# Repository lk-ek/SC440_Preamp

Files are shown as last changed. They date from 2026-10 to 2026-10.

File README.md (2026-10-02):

# SC440 OPA1678 microphone preamp

## don't try this at home

Caveat: measurements show that the theoretical use for this preamp is a
reduction of the noise floor by a whopping 0.2dB. The noise seems to come from
either the capsule or the analog board.

So this is a nice flex mod as an exercise in analogue circuitry, but don't
expect any quality gains from it at all.

## Intro

A 5 V analog gain board for the **t.bone SC 440 USB microphone**. It sits between
its original microphone/JFET board and USB/ADC board, AC-couples the signal,
rebiases it around a buffered half-supply reference, and adds selectable gain.
The aim is to use less gain in the following ADC stage. A reduction in overall
recording noise depends on how much noise that stage contributes; microphone
and original analog-board noise are amplified along with the signal.

**Default in the current KiCad files:** amplifier gain +10.10 dB, using R8 = 2.2 kΩ and
R9 = 1 kΩ, with the C2 = 1 µF MLCC input option. C1, R1 and R2 are DNP.
C9 = 330 pF is populated across R8.

The board outline is **30 × 35 mm**, with 2 mm corner radii. PCB thickness in
this project is **1.6 mm**. Files were saved with **KiCad 10.99 nightly**; use a
build that supports their file format.

- [Assembly choices: gain and input capacitor](#assembly-choices)
- [Bill of materials](#bill-of-materials)
- [Connections and installation](#connections-and-installation)
- [Circuit and test points](#circuit-and-test-points)
- [Views](#views)
- [Simulation](#simulation)
- [Regenerating the README images](#regenerating-the-readme-images)

## Assembly choices

### Gain: approximately 6, 8 or 10 dB

The non-inverting amplifier uses `Av = 1 + R8/R9`, with R9 fixed at **1 kΩ**.
Populate one R8 value; these are alternatives, not additional resistors.

| Variant | R8 | R9 | Voltage gain | Gain | Concrete R8 example, Yageo thin film |
|---|---:|---:|---:|---:|---|
| 6 dB | 1 kΩ | 1 kΩ | 2.0× | +6.02 dB | `RT0805BRD071KL` |
| 8 dB | 1.5 kΩ | 1 kΩ | 2.5× | +7.96 dB | `RT0805BRD071K5L` |
| **10 dB — CAD default** | **2.2 kΩ** | **1 kΩ** | **3.2×** | **+10.10 dB** | `RT0805BRD072K2L` |

The table gives the amplifier gain. End-to-end gain from J2 pin 4 to J1 pin 4
is slightly lower: R4/R6 alone introduce about 0.086 dB attenuation. The
unloaded AC model gives approximately **5.93 / 7.87 / 10.01 dB at 1 kHz**
for the default MLCC option. See [SIMULATION_VALIDATION.md](SIMULATION_VALIDATION.md)
for both capacitor options and the 20 kHz results.

These parts are 0805, 0.1%, 25 ppm/°C, 0.125 W. Ordinary 1% resistors also work;
thin film is preferred for R8/R9 for ratio stability and low excess noise.
Thin film does not eliminate thermal noise. The lower resistance values reduce
that contribution compared with the older 22 kΩ/10 kΩ pair.

Use 6 dB where input-level headroom matters most; 10 dB provides the greatest
analog boost. For a fixed ADC clipping level, allowable microphone-board input
amplitude is inversely proportional to the selected voltage gain. Reduce ADC
gain to obtain comparable recording levels, then check loud speech and plosives.
An analog booster does not increase the ADC's full-scale voltage.

**C9 remains 330 pF for all three variants.** Its feedback-network pole is
approximately 482 kHz / 322 kHz / 219 kHz for 6 / 8 / 10 dB respectively. This
reduces the ideal amplifier gain toward unity at high frequencies; it is not a
filter whose gain falls to zero. Its calculated contribution at 20 kHz is only
about −0.006 / −0.014 / −0.032 dB respectively, before other circuit roll-off.

### Input coupling: MLCC or film

Choose exactly one of the following assemblies. The input resistor R4 and bias
resistor R6 are unchanged for either option.

| Part | **A — compact MLCC, CAD default** | **B — film** |
|---|---|---|
| C2 | **1 µF, 0805, X7R**, ≥16 V | **DNP** |
| C1 | DNP | **2.2 µF PET film**, Faratronic `C241J225J2SC000`, 63 V, 5 mm pitch |
| R1, R2 | DNP | **0 Ω each**, 0805 |
| R4 | 1 kΩ | 1 kΩ |
| R6 | 100 kΩ | 100 kΩ |
| Approximate input high-pass pole | 1.6 Hz | 0.72 Hz |

The default path is C2 → R4 → IN_AC. The film path is
R1 → C1 → R2 → R4 → IN_AC. Do not populate both coupling branches: the two
capacitors would operate in parallel rather than select a single option.

Both coupling capacitors are non-polarized. Film avoids the ferroelectric
voltage dependence and microphony of X7R, but takes more space. The MLCC option
is the compact assembly; its effective capacitance depends on the exact part
and bias. These differences do not by themselves establish an audible benefit
in the complete microphone.

The film variant requires assembly changes only. If editing KiCad to represent
that variant, mark C2 DNP and clear DNP on C1/R1/R2, then update the PCB from the
schematic. C1/R1/R2 are currently excluded from simulation as well, so changing
DNP flags alone is not sufficient to simulate the film path.

## Bill of materials

Quantities below are **per preamp PCB**. They describe the current electrical
values and footprints. Orderable examples are documented choices, not proof
that those exact manufacturers are already installed. Equivalent parts must
match value, dielectric/technology, package and mechanical clearance.

All SMD passives use **0805 hand-solder footprints**. Resistor examples are
0.125 W. No special “audio-grade” electrolytics are needed. Prices and stock
are intentionally not fixed in this BOM.

### Common parts for all six gain/capacitor combinations

| Ref. | Qty | Value / specification | Package / assembly side | Concrete part or ordering specification |
|---|---:|---|---|---|
| U1 | 1 | OPA1678 dual audio op-amp | SOIC-8, 3.9 × 4.9 mm, 1.27 mm pitch; front | **Texas Instruments `OPA1678IDR`**; do not substitute VSSOP/SON versions |
| R3 | 1 | 22 Ω, 1% | 0805; front | Yageo `RC0805FR-0722RL` |
| R4, R9 | 2 | 1 kΩ; thin film, 0.1% recommended | 0805; front | Yageo **`RT0805BRD071KL`**; thin film at R4 is optional |
| R5, R7 | 2 | 10 kΩ, 1% | 0805; front | Yageo `RC0805FR-0710KL` |
| R6 | 1 | 100 kΩ, 1% | 0805; front | Yageo `RC0805FR-07100KL` |
| R8 | 1 | **Select 1 kΩ / 1.5 kΩ / 2.2 kΩ** | 0805; front | Select exactly one part from the gain table above |
| R10 | 1 | 100 Ω, 1% | 0805; front | Yageo `RC0805FR-07100RL` |
| C3 | 1 | 47 µF, 16 V, ±20%, polarized | Radial, Ø5 × 11 mm, 2 mm pitch; front | **Aishi `ERS1CM470D11OT`**, [LCSC C160836](https://www.lcsc.com/product-detail/C160836.html), matching the schematic link |
| C4, C8 | 2 | 100 nF, X7R, ±10%, ≥16 V | 0805; **C4 front, C8 back** | Example: Murata `GRM21BR71H104KA01L`, 50 V |
| C5, C9 | 2 | 330 pF, **C0G/NP0**, ±5% | 0805; front | Example: Murata **`GRM2165C2A331JA01D`**, 100 V |
| C6 | 1 | 10 µF, 16 V, ±20%, polarized | Radial, Ø5 × 11 mm, 2 mm pitch; front, **mount lying down** | **Chengx `KM106M016D11RR0VH2FP0`**, [LCSC C43799](https://www.lcsc.com/product-detail/C43799.html), matching the schematic link |
| C7 | 1 | 1 nF, **C0G/NP0**, ±5% | 0805; front | Example: Murata **`GRM2165C2A102JA01D`**, 100 V |
| J1 | 1 | 4-pin JST XH header to digital board | **2.50 mm**, vertical/top-entry; back | **JST `B4B-XH-A`**; RoHS/tinning suffix may be shown as `(LF)(SN)` |
| J2 | 1 | 4-pin male header to analog board | **2.54 mm**, straight; back | 1×4, 0.64 mm square pins; cut from a standard strip; choose mating length to suit original socket and board spacing |
| TP1–TP5 | 5 PCB pads | Test pads, no purchased component required | 1 × 1 mm THT pad, 0.5 mm drill; front | Optional fine wire for probing; not five additional headers |

**C4 and C8 are required bypass capacitors and are included in the BOM.** Their
previous exclusion flags have been cleared in the root schematic, PCB and
synchronized AC schematic.

C3 alternative: **Rubycon `35ZLH47MEFC5X11`**, 47 µF / 35 V, Ø5 × 11 mm,
2 mm pitch, [LCSC C109390](https://www.lcsc.com/product-detail/C109390.html).
It fits the nominal pad pitch/body diameter and is electrically suitable;
ZLH is a low-impedance series, not a dedicated low-leakage series. The higher
voltage rating is not necessary here. Low leakage is useful at VREF_RAW, but a
standard good-quality aluminum electrolytic is sufficient for this application.

### Add parts for exactly one input option

| Variant | Ref. | Qty | Specification | Concrete example |
|---|---|---:|---|---|
| **A — MLCC** | C2 | 1 | 1 µF, X7R, ±10%, 0805, ≥16 V | Murata **`GRM219R71E105KA88D`**, 25 V |
| **B — film** | C1 | 1 | 2.2 µF, PET, ±5%, 63 V, 5 mm lead pitch | Faratronic **`C241J225J2SC000`**, [LCSC C5372007](https://www.lcsc.com/product-detail/C5372007.html) |
| **B — film** | R1, R2 | 2 | 0 Ω links, 0805 | Yageo **`RC0805JR-070RL`**, or suitable solder bridges |

The MLCC assembly has **14 SMD passives and two radial electrolytics**. The film
assembly has **15 SMD passives, two radial electrolytics and one film capacitor**.
Both also use U1, J1 and J2. Simulation sources and XREF1/XAMP1 are not physical
parts to order.

### Cable, original-board modification and mechanical supports

| Item | Qty per complete installation | Concrete choice / notes |
|---|---:|---|
| Additional digital-board header | 1 | JST **`B4B-XH-A`**, if replacing the original digital-board socket as described below; verify its hole spacing separately |
| Cable housings | 2 | JST **`XHP-4`**, 4 positions |
| Crimp contacts | 8 | JST **`SXH-001T-P0.6`**, for 22–28 AWG wire; use the matching crimp tooling, or a correctly wired premade XH cable |
| Cable conductors | 4 | Short flexible wires; verify pin-to-pin continuity rather than trusting wire colors |
| Replacement analog-board header | As required | Standard 2.54 mm 1×4 header; original connector relocation is part of the installation, not an extra gain-stage component |
| PCB-only support footprints | 2, optional mechanical population | Two back-side **1×2, 2.54 mm pin sockets**, currently both called `REF**`; their pads have **no electrical nets**. Select height to suit the original board or leave unpopulated if not needed for support |

Part references: [TI OPA1678 datasheet](https://www.ti.com/lit/ds/symlink/opa1678.pdf),
[JST XH datasheet](https://www.jst-mfg.com/product/pdf/eng/eXH.pdf),
[Yageo 2.2 kΩ RT specification](https://www.yageogroup.com/component-documentation/download/specsheet/RT0805BRD072K2L),
[Yageo 1.5 kΩ RT specification](https://www.yageogroup.com/component-documentation/download/specsheet/RT0805BRD071K5L),
[Yageo 1 kΩ RT specification](https://www.yageogroup.com/component-documentation/download/specsheet/RT0805BRD071KL),
[Murata MLCC catalog, including C0G parts](https://www.mouser.com/datasheet/2/281/murata_mure-s-a0000034126-1-1740300.pdf),
and [Murata 100 nF specification](https://search.murata.co.jp/Ceramy/image/img/A01X/G101/ENG/GRM21BR71H104KA01-01.pdf).
See [FOOTPRINT_CHECK.md](FOOTPRINT_CHECK.md) for the actual symbol/pad/device cross-check.

## Connections and installation

### Connector pinout

**J1 is the digital-board connector; J2 is the analog-board connector.** Both
are installed on the **back** of this PCB. The two pitches differ: JST XH is
2.50 mm, the unshrouded analog header is 2.54 mm.

| Pin number | J2 — from analog board | J1 — to digital board | Connection on this PCB |
|---|---|---|---|
| 1 | GND | GND | Direct common ground |
| 2 | LED | LED | Direct pass-through |
| 3 | +5V | +5V | Direct pass-through; preamp supply branches through R3 |
| 4 | ANALOG_INPUT | ANALOG_OUTPUT | Through coupling capacitor, amplifier and R10; **not** direct |

Use pad numbers, including the square pin-1 pad, rather than assuming a
left-to-right order from a photograph. Back-side placement and mirrored views
change the apparent order. Check the cable at both ends before connecting USB.

The intended installation mounts the daughterboard behind the original analog
PCB. Remove/reposition the original analog-board pin headers to the opposite
side to make the required board-to-board connection. Replace the original
digital-board pin socket with a JST XH header and use a short 4-wire cable to
J1. Verify actual original-board holes, mating parts and enclosure clearance
before final soldering; the daughterboard files do not define those original
board footprints.

**Keep the existing series DC-blocking capacitor on the digital-board audio
input.** J1 pin 4 carries the amplified AC signal on a DC level near VREF. There
is no output coupling capacitor on the daughterboard itself. The microphone's
exact ADC-side connection must be checked on the physical digital board.

C6 needs to be mounted **lying down** in the intended enclosure. Its CAD model
is a generic upright radial capacitor, so the 3D view is not the final assembly
orientation. Preserve polarity, avoid stressing the lead seals, and keep the
body/metalwork clear of exposed conductors. Check C3 and the optional C1 against
available height too. C1 currently has no attached 3D model.

## Circuit and test points

| Block | Actual parts / connections | Purpose / approximate behavior |
|---|---|---|
| Supply filter | R3 = 22 Ω; C6 = 10 µF and C8 = 100 nF from VCC_A to GND | Filters raw USB 5 V; ideal R3/C6 pole ≈723 Hz |
| Reference divider | R5 = 10 kΩ from VCC_A to VREF_RAW; R7 = 10 kΩ to GND; C3 = 47 µF and C4 = 100 nF to GND | Approximately VCC_A/2; divider/C3 pole ≈0.68 Hz |
| Reference buffer | U1B: pin 5 at VREF_RAW, pins 6/7 at VREF | Low-impedance reference for input bias and feedback |
| Input coupling / bias | C2 or C1/R1/R2; R4 = 1 kΩ; R6 = 100 kΩ to VREF | Blocks original-board DC and establishes the amplifier bias |
| Input RF filter | R4 with C5 = 330 pF from IN_AC to GND | Pole approximately 0.48 MHz for a low-impedance source; source impedance also matters |
| Amplifier | U1A; R8 from PREAMP_OUT to FB, R9 from FB to VREF | Gain selected by R8/R9 |
| Feedback HF shaping | C9 = 330 pF parallel to R8 | Gradually reduces gain toward unity above the feedback pole |
| Output isolation / filter | R10 = 100 Ω; C7 = 1 nF from ANALOG_OUTPUT to GND | Isolates capacitive cable/input load; ideal RC pole ≈1.59 MHz |

These pole calculations describe individual networks, not the complete loaded
frequency response. Cable/ADC loading and the op-amp's finite bandwidth also
contribute. Do not add a large capacitor directly to the buffered VREF output
without checking the buffer's capacitive-load stability; C3/C4 are on VREF_RAW.

| Test pad | Net | Expected DC with USB connected, no audio |
|---|---|---|
| TP1 | VCC_A | Raw +5V minus the drop across R3; **at least 4.5 V** for OPA1678 operation |
| TP2 | VREF_RAW | Approximately TP1/2 |
| TP3 | VREF | Approximately TP2 |
| TP4 | PREAMP_OUT | Approximately TP3 |
| TP5 | GND | Probe reference |

Raw USB voltage was reported above 4.9 V. At roughly 4.2 mA quiescent draw the
22 Ω resistor drops about 0.09 V; this is an estimate, not a minimum-voltage
measurement at the IC. Check TP1 under operation. The input signal is centered
near half supply; OPA1678 is not rail-to-rail at its inputs.

For commissioning, first check power and reference voltages, then compare
recordings at equal final level with reduced ADC gain. Check clipping with loud
speech/plosives and look for USB-related spurs. A valid rendering or simulated
trace does not replace those measurements.

## Views

The included images represent the saved default assembly (10 dB, MLCC).

### Schematic

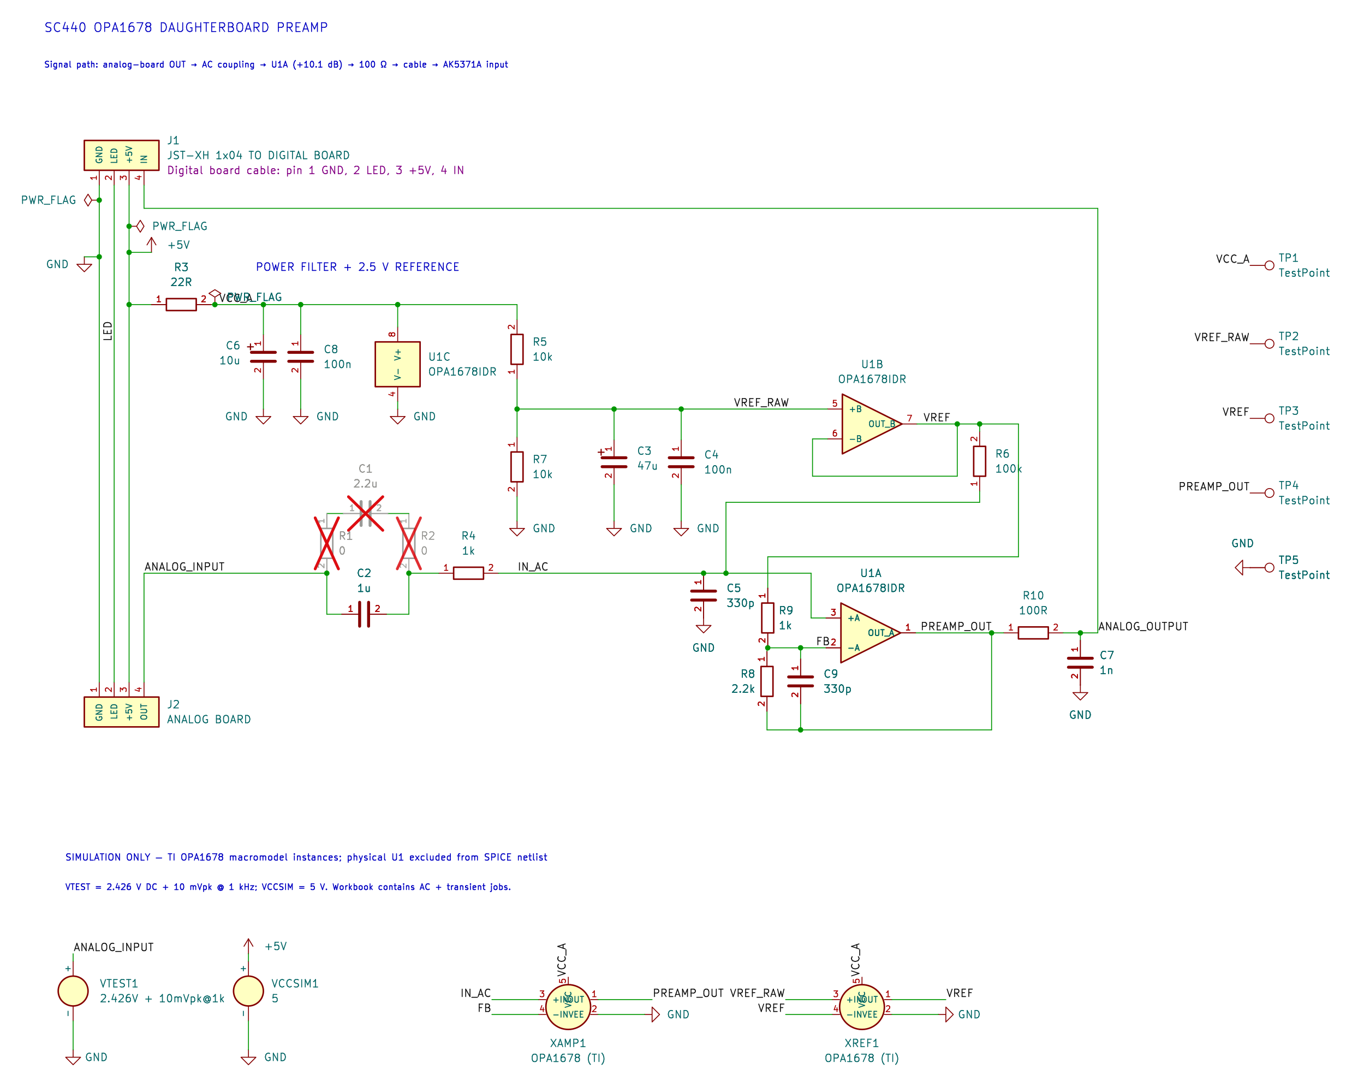
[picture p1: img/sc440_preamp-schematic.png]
Schematic


### PCB layout — front

Copper, front silkscreen and board outline.

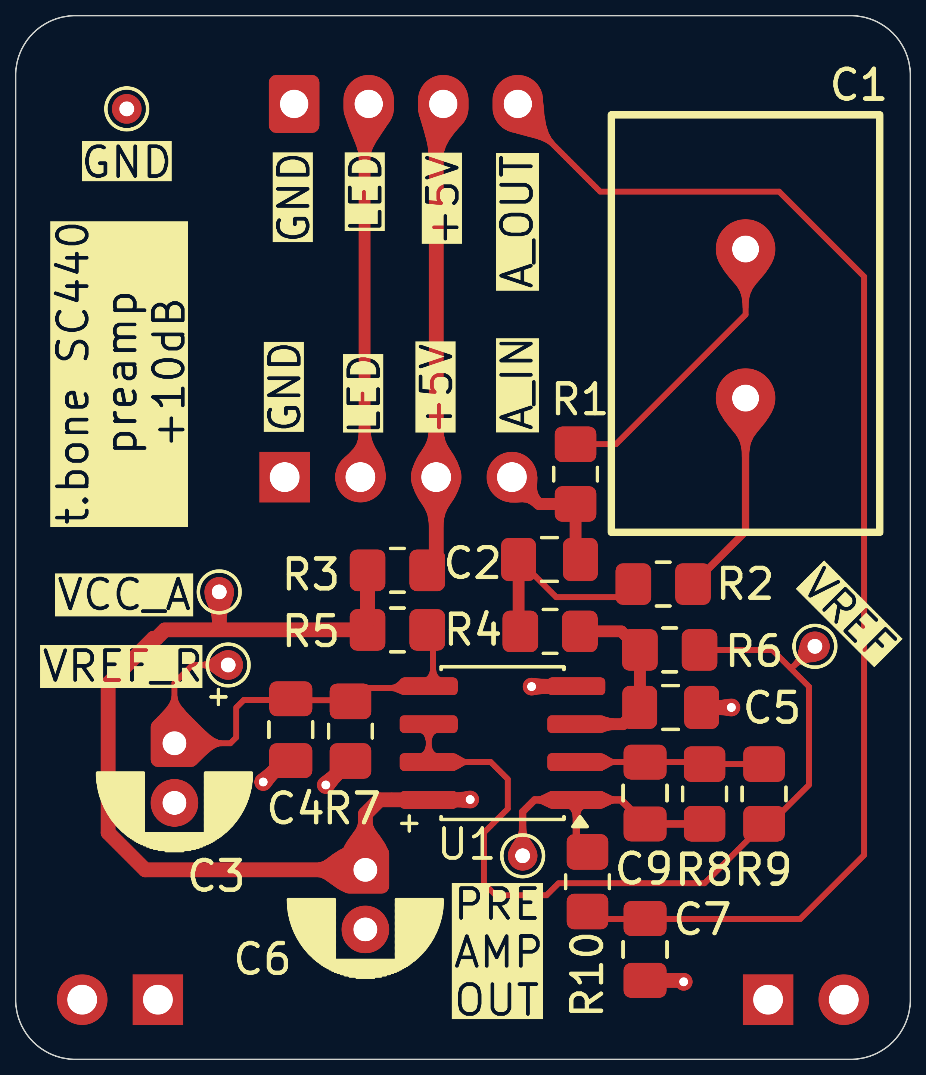
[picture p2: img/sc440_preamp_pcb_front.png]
PCB layout — front


### PCB layout — back

Rear copper/silkscreen and board outline, mirrored as viewed from the back.

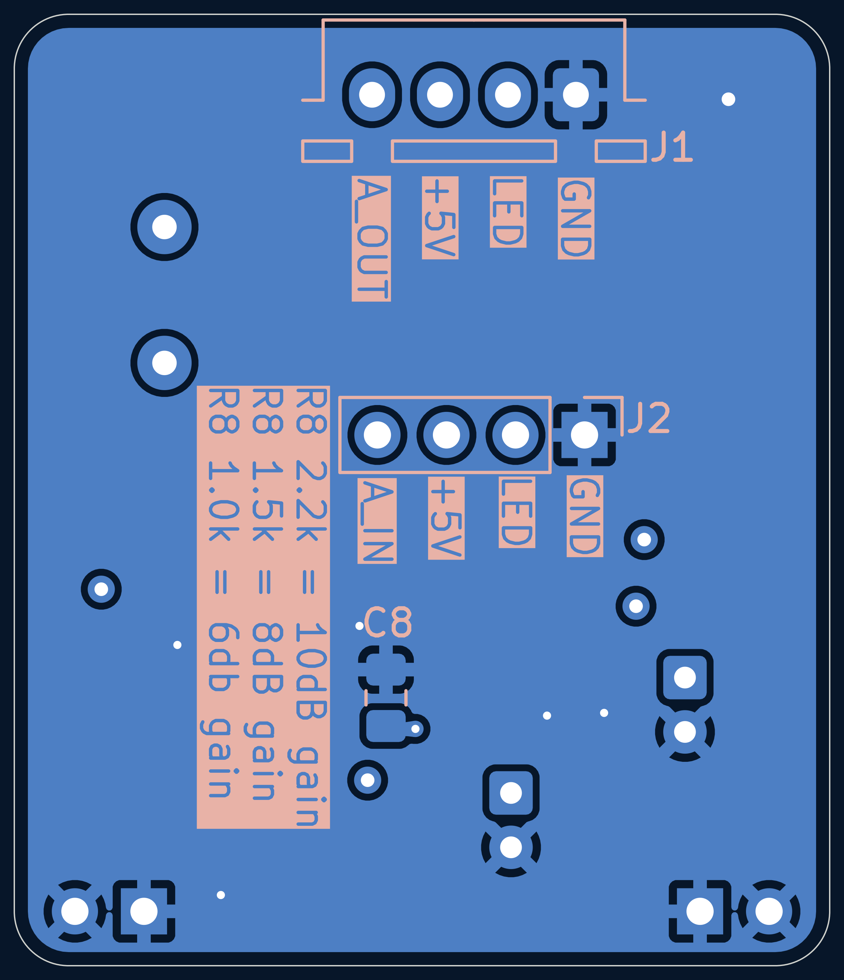
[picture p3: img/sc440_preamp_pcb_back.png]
PCB layout — back


### 3D — front and back

DNP models are omitted. C6's generic upright model and C1's missing model mean
these images do not establish enclosure fit for every assembly variant.

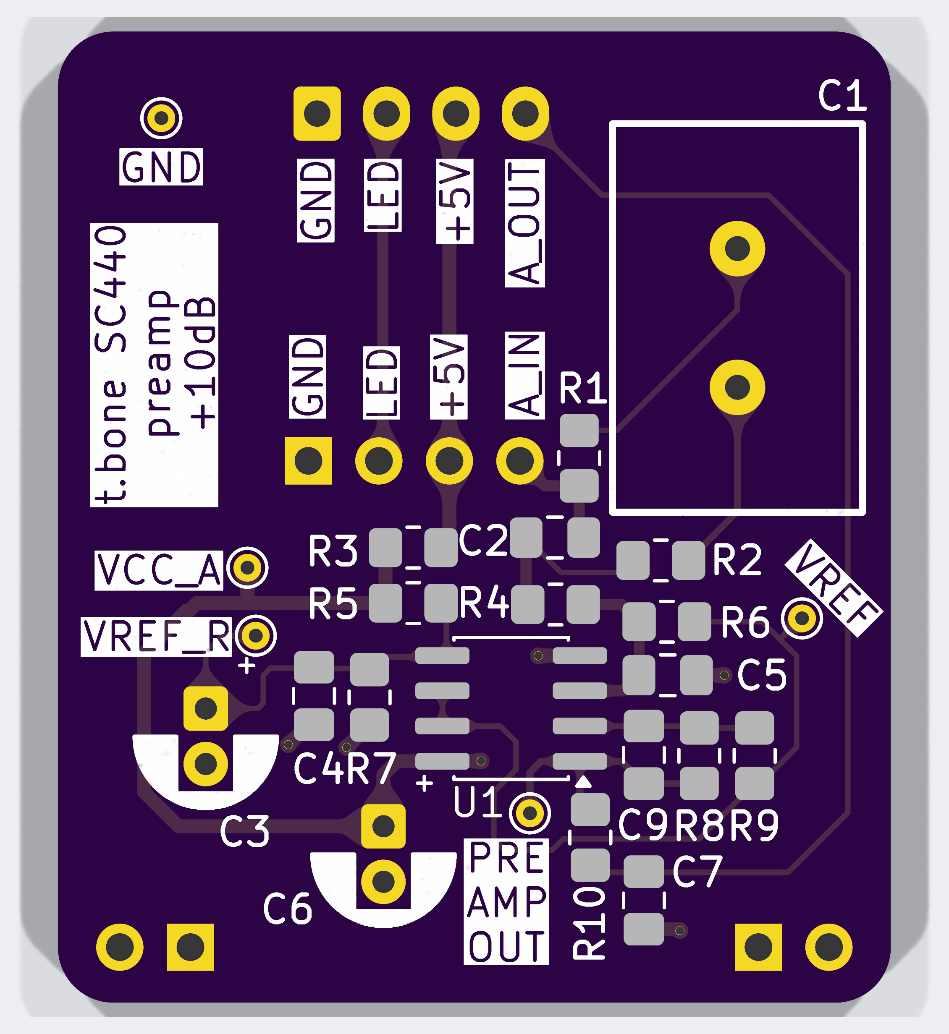
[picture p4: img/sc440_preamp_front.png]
3D front

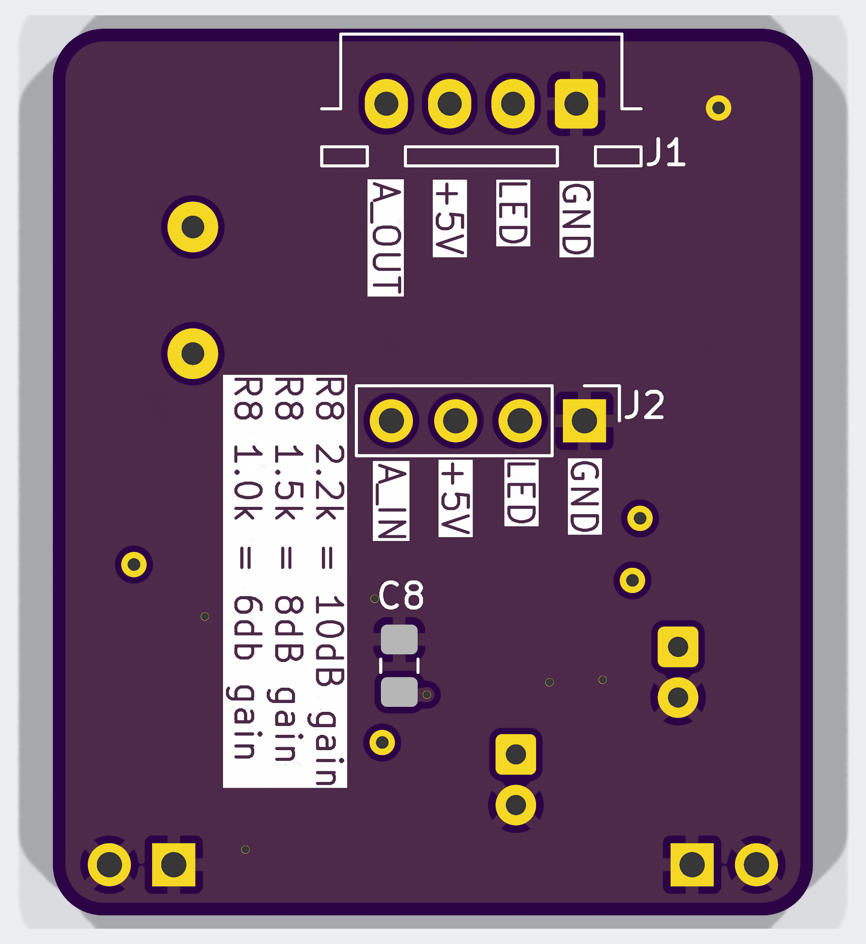
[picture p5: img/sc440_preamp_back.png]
3D back


## Simulation

There are two model paths. **Both schematics and both reference netlists now
use the current hardware topology and component references.** The AC project
was derived from the root schematic, with its AC-model properties, simulation
annotations and project metadata adapted.

| File / project | Status in this revision | Appropriate use |
|---|---|---|
| Root `SC440_Preamp.kicad_sch` + `.wbk` | Current root hardware values, including 2.2 kΩ/1 kΩ, R4/C5/C7/C9; default MLCC path | Transient / operating-point work after preparing the local TI model; not newly executed for this documentation update |
| `AC_SIM/SC440_Preamp_AC.kicad_sch` + `.wbk` | Current root topology; self-contained AC model; workbook plots output gain/phase | Current unloaded small-signal response for the default 10 dB / MLCC assembly |
| `SC440_Preamp_fallback.cir` | Current topology and references, including input/output filters and C9 | Transient fallback after preparing the TI model |
| `AC_SIM/SC440_Preamp_AC_reference.cir` | Current topology and references | Standalone AC analysis using the included model |

The root schematic uses a local ngspice adaptation of TI's **OPA167x TINA-TI
Spice Model (SBOMAC5D)**. Download it from the
[TI OPA1678 product page](https://www.ti.com/product/OPA1678), then run **from the
project root**:

```sh
python3 tools/prepare_ti_model.py ~/Downloads/sbomac5d.zip
```

This creates `vendor/OPA167x_ngspice.LIB`. The TI model is not shipped here.
The converter recognizes the documented Final 1.6 source hash; syntax adaptation
does not guarantee compatibility with every KiCad/ngspice version. The modified
noise and protection cells are not vendor-accurate. Treat the prepared model as
a simulation aid, not proof of measured noise or protection performance.

The AC model is project-authored and self-contained, with typical 114 dB
open-loop gain and 16 MHz GBW. It does not model clipping, slew, noise or rail
limits. Both AC files default to 10 dB / MLCC; change their R8/input assembly
when investigating other variants. Cable and ADC loading are not modeled. See
[SIMULATION_SPLIT.md](SIMULATION_SPLIT.md) and [AC_SIM/README.md](AC_SIM/README.md).
All six assembly variants were run with **ngspice 42** using the included AC
model. Results and validation limits are in
[SIMULATION_VALIDATION.md](SIMULATION_VALIDATION.md). Model setup details are in
[SIMULATION_MODEL.md](SIMULATION_MODEL.md).

## Regenerating the README images

Save schematic and PCB changes in KiCad first. The generator reads the saved
files, refills zones in a temporary PCB copy, exports each PCB side separately,
and renders the 3D component sides with KiCad's `top`/`bottom` views.

Install Python, Pillow and Inkscape. From the project root:

```sh
python3 -m venv .venv
source .venv/bin/activate
python -m pip install Pillow
python tools/regenerate_readme_images.py \
  --kicad-cli "/Applications/KiCad-nightly-260925/KiCad.app/Contents/MacOS/kicad-cli" \
  --inkscape "/Applications/Inkscape.app/Contents/MacOS/inkscape"
```

Those app paths are the current macOS example; adjust them for your installation.
The script can discover common app/PATH locations automatically. Use
`--models-dir PATH` if the installed 3D library cannot be resolved. It normally
rejects missing model files; `--allow-missing-models` explicitly allows incomplete
renders. DNP footprints' models are omitted automatically.

No KiCad source file is rewritten by the image generator. Images are staged and
validated before replacement. The old combined PCB image reference, if present,
is converted to front/back references in README.md only after successful exports.
For more detail on PCB views, override `--pcb-front-layers` and
`--pcb-back-layers`; fabrication/courtyard layers are omitted by default to keep
these views readable.

## Licensing and model redistribution

Project-authored content is **GPL-3.0-only**, except where separately noted:
[LICENSE.md](LICENSE.md), [LICENSES/GPL-3.0-only.txt](LICENSES/GPL-3.0-only.txt).
No TI SPICE macro-model is included or relicensed. See
[THIRD_PARTY_NOTICES.md](THIRD_PARTY_NOTICES.md) and [vendor/README.md](vendor/README.md).

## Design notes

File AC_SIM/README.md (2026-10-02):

# Current-hardware AC simulation

`SC440_Preamp_AC.kicad_sch` now contains the same hardware topology, component
references and default assembly as the root schematic: **R8 = 2.2 kΩ,
R9 = 1 kΩ, C2 = 1 µF**, input filter R4/C5, output filter R10/C7, and
**C9 = 330 pF** across R8. C1/R1/R2 remain DNP/excluded from simulation.
C4 and C8 are included in the BOM.

The schematic was copied from the current root project; the two virtual
op-amp symbols were changed to the included project-authored
`vendor/OPA1678_AC_ngspice.lib`. No TI macro-model is required. The AC model is
GPL-3.0-only, not a TI model, and does not model clipping, slew, noise,
rail limits or power-supply rejection.

Open this directory's `.kicad_pro`, then the schematic's simulator, and load
`SC440_Preamp_AC.wbk` if necessary. The workbook sweeps **0.1 Hz to 10 MHz** and
shows ANALOG_OUTPUT gain/phase plus PREAMP_OUT gain. The source has **AC = 1 V**,
so output-voltage magnitude in dB directly gives end-to-end gain in dB. Keep that
normalization when comparing traces; the 1 V small-signal AC excitation is not
an intended real microphone amplitude.

The standalone `SC440_Preamp_AC_reference.cir` has the same current topology:

```sh
cd AC_SIM
ngspice SC440_Preamp_AC_reference.cir
```

At the ngspice prompt, run `run`, then for example
`plot vdb(ANALOG_OUTPUT)` or `plot vp(ANALOG_OUTPUT)`. ADC/cable loading and
original-board source impedance are not modeled. The signal generator is ideal.

## Other gain and coupling assemblies

R9 remains 1 kΩ. Change **R8** in the AC schematic or reference netlist:

| R8 | Nominal amplifier gain |
|---:|---:|
| 1 kΩ | +6.02 dB |
| 1.5 kΩ | +7.96 dB |
| 2.2 kΩ | +10.10 dB |

These are amplifier gains; end-to-end gain includes the input/output networks.
Standalone ngspice results for all six assemblies are in
[../SIMULATION_VALIDATION.md](../SIMULATION_VALIDATION.md).

C9 stays 330 pF. To simulate the film assembly in the schematic, exclude C2
from simulation and mark it DNP; enable C1/R1/R2 by clearing both DNP and
“Exclude from simulation”, with C1 = 2.2 µF and R1/R2 = 0 Ω. In the reference
netlist, replace the C2 line with `C1 ANALOG_INPUT COUPLED 2.2u`; this represents
both links as ideal wires. Change both representations if keeping them in sync.

See [../SIMULATION_SPLIT.md](../SIMULATION_SPLIT.md) for model pin maps and
validation scope, and [../README.md](../README.md) for the hardware BOM.

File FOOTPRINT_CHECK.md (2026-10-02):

# Symbol, pad and device cross-check

This document describes the actual root schematic and PCB in the 2026-10-02
revision. Root and AC schematic references are now identical. The checks below
cover pin assignment, nominal pad geometry and assembly flags; they are not a
replacement for a KiCad DRC or an enclosure-fit measurement.

## U1 — Texas Instruments OPA1678IDR

Source: [TI OPA167x datasheet](https://www.ti.com/lit/ds/symlink/opa1678.pdf),
OPA1678 D-package pinout and SOIC drawing. `IDR` is the SOIC-8 version. VSSOP
(`IDGKR`) and SON versions do not fit this PCB.

The embedded `SC440_Preamp:OPA1678` symbol, numbered PCB pads and TI device
pins agree:

| Symbol pin | PCB pad | TI device function | PCB net |
|---:|---:|---|---|
| 1 | 1 | OUT A | PREAMP_OUT |
| 2 | 2 | −IN A | FB |
| 3 | 3 | +IN A | IN_AC |
| 4 | 4 | V− | GND |
| 5 | 5 | +IN B | VREF_RAW |
| 6 | 6 | −IN B | VREF |
| 7 | 7 | OUT B | VREF |
| 8 | 8 | V+ | VCC_A |

Footprint: `Package_SO:SOIC-8_3.9x4.9mm_P1.27mm`. Adjacent pads are spaced
1.27 mm; the nominal body is 3.9 × 4.9 mm. The B amplifier is a follower,
with pads 6 and 7 on the same VREF net. U1's physical units are excluded from
simulation; XAMP1/XREF1 provide the simulated amplifiers and are not BOM parts.

### AC simulation alias pin order

The five-pin `OPA1678_SIM` symbol is a virtual simulation symbol, not U1's
physical package. Its pin map into the included AC model is:

| Virtual symbol pin / function | AC subcircuit position |
|---|---:|
| 1 / OUT | 5 |
| 2 / VEE | 4 |
| 3 / +IN | 1 |
| 4 / −IN | 2 |
| 5 / VCC | 3 |

Thus `Sim.Pins = 1=5 2=4 3=1 4=2 5=3` for the subcircuit order
`INP INM VCC VEE OUT`. Do not reuse the older AC schematic's alias mapping
with the current embedded symbol. The root TI model uses the corresponding
named map `1=OUT 2=VEE 3=IN+ 4=IN- 5=VCC`.

## Connectors — installed on B.Cu

| Symbol / pad number | J1 — digital-board side | J2 — analog-board side |
|---:|---|---|
| 1 | GND | GND |
| 2 | LED | LED |
| 3 | +5V | +5V |
| 4 | ANALOG_OUTPUT | ANALOG_INPUT |

The custom embedded connector symbols use these numbered pins. Both connector
PCB footprints have a square pad 1. Mounting on the back changes the visible
left-to-right order; continuity and pad numbers define wiring.

- **J1:** `Connector_JST:JST_XH_B4B-XH-A_1x04_P2.50mm_Vertical`, top-entry,
  2.50 mm pitch, four pads spanning 7.50 mm. Matches the four-circuit top-entry
  **JST B4B-XH-A** in the [JST XH drawing](https://www.jst-mfg.com/product/pdf/eng/eXH.pdf).
  This is not the older side-entry S4B footprint. Mates with XHP-4 and suitable
  XH crimp contacts.
- **J2:** `Connector_PinHeader_2.54mm:PinHeader_1x04_P2.54mm_Vertical`, straight
  1×4 generic header, 2.54 mm pitch; pads span 7.62 mm. There is no exact
  manufacturer part assigned. Choose square-pin length and insulator height
  to suit the original microphone PCB and mating connector.
- **Two `REF**` footprints:** back-side 1×2 sockets with 2.54 mm pitch, absent
  from the schematic. All four pads have no electrical net. They are mechanical
  supports/placeholders, not additional signal connectors. Manufacturer and
  required height are not specified.

The original microphone-board footprints are outside this project. In
particular, the new header on the digital board must be checked against its
actual holes; a 2.54 mm original header is not exactly JST XH's 2.50 mm pitch.

## Passive geometry and polarity

| Parts | Actual footprint | Check / assembly |
|---|---|---|
| R1–R10 | `Resistor_SMD:R_0805_2012Metric_Pad1.20x1.40mm_HandSolder` | 0805 SMD parts; the old Yageo MFR through-hole datasheet links in the schematic are stale metadata, not ordering guidance |
| C2, C4, C5, C7, C8, C9 | `Capacitor_SMD:C_0805_2012Metric_Pad1.18x1.45mm_HandSolder` | Non-polarized 0805; C4 is front-side, C8 back-side; both included in BOM |
| C3 | `Capacitor_THT:CP_Radial_D5.0mm_P2.00mm` | Pad 1 = VREF_RAW (+); pad 2 = GND (−); schematic-linked Aishi ERS1CM470D11OT listing gives Ø5 × 11 mm, 2 mm pitch |
| C6 | Same radial footprint | Pad 1 = VCC_A (+); pad 2 = GND (−); schematic-linked Chengx KM106M016D11RR0VH2FP0 listing gives Ø5 × 11 mm, 2 mm pitch; install lying down for the intended enclosure |
| C1 | Project-local `Faratronic_C241J225_P5.00mm` | Non-polarized; pad 1 via R1 to ANALOG_INPUT; pad 2 via R2 to the input side of R4 |

All components in the gain tables and BOM match these nominal package sizes.
The [Yageo RT 2.2 kΩ part specification](https://www.yageogroup.com/component-documentation/download/specsheet/RT0805BRD072K2L)
confirms the recommended resistor's 0805 dimensions and technology. The
[Murata catalog](https://www.mouser.com/datasheet/2/281/murata_mure-s-a0000034126-1-1740300.pdf)
confirms the selected 330 pF / 1 nF C0G parts' 2.0 × 1.25 mm body size.
Exact electrolytic part specifications are linked in the README; dimensional
checks here use their published supplier listings, not a separately retrieved
manufacturer approval drawing.

### C1 custom footprint

Source: [Faratronic C24 / CL23B manufacturer series drawing](https://datasheet.lcsc.com/datasheet/pdf/98aa4bc32419fc2b11d6d8f0ae52cac7.pdf?productCode=C545501),
pattern II, `C241J225-2S…` (2.2 µF / 63 V): nominal **W = 7.2 mm,
H = 11.0 mm, T = 6.0 mm**, **P = 5.0 mm**, lead diameter **0.6 mm**.
This corresponds to the specified `C241J225J2SC000` family/packaging choice.

The local footprint has pad centers at (0,0) and (5,0), **0.9 mm drills**, and
2 mm pads. Its 13.5 × 8.5 mm fabrication outline and 14.4 × 9.4 mm courtyard
are deliberately larger than the nominal upright body plan. They are not the
actual body dimensions. The 11 mm body height still needs enclosure clearance;
a lying-down arrangement needs a different mechanical envelope. No C1 3D model
is attached, so a rendered film assembly cannot confirm body clearance.

## Assembly variants

- Default MLCC: C2 populated; C1/R1/R2 DNP.
- Film: C2 DNP; C1/R1/R2 populated, with R1/R2 = 0 Ω.
- R9 = 1 kΩ for all gain options; only R8 changes to 1 / 1.5 / 2.2 kΩ.
- C9 = 330 pF is populated in the current design, not a missing optional 100 pF
  part. C4/C8 are included in both the schematic and PCB BOM flags.

No connector geometry, routed track, pad or board outline was changed during
this documentation/simulation update. Only C4/C8 BOM flags were corrected in
the physical design files.

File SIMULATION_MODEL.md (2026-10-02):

# TI OPA167x transient model setup

The root schematic and `SC440_Preamp_fallback.cir` reference the locally
generated `vendor/OPA167x_ngspice.LIB`. The Texas Instruments **OPA167x TINA-TI
Spice Model (SBOMAC5D)** is not included in this repository.

Download it from the [TI OPA1678 product page](https://www.ti.com/product/OPA1678),
then run from the project root:

```sh
python3 tools/prepare_ti_model.py /path/to/sbomac5d.zip
```

The converter expects this source:

- OPA167x model version Final 1.6.
- SHA-256 `c130cbd159cc72e36dc9fb368c2491cee6329a5312ed3c85641c7b8492433391`.
- Subcircuit order `OPA167x IN+ IN- VCC VEE OUT`.

`--allow-untested` bypasses the source-hash check; it does not make a different
model compatible. Inspect the generated changes before using that option.

## What the included converter actually does

`tools/prepare_ti_model.py` currently:

- removes TINA/PSpice `PARAMS:` markers;
- translates the expected `VSWITCH` models into ngspice `SW` models;
- translates the overload-sense boolean OR syntax;
- replaces the TINA noiseless-resistor declaration with a generic resistor model;
- replaces the named self-controlled ESD switch subcircuits with diode clamps.

These edits are syntax/convergence adaptations, not a guarantee that every
nested behavioral subcircuit works with every ngspice compatibility mode.
In particular, a “Too many parameters for subcircuit” error must be resolved
before treating simulation output as valid; removing `PARAMS:` alone is not
proof of parameter compatibility. The script itself was not changed during
this documentation/AC synchronization update.

## Current root wiring

The five-pin virtual symbol has pin 1 OUT, 2 VEE, 3 +IN, 4 −IN, 5 VCC.
Its TI-model mapping is `1=OUT 2=VEE 3=IN+ 4=IN- 5=VCC`. Intended model calls:

```spice
XREF1 VREF_RAW VREF VCC_A 0 VREF OPA167x
XAMP1 IN_AC FB VCC_A 0 PREAMP_OUT OPA167x
```

Root hardware values are R8 = 2.2 kΩ and R9 = 1 kΩ, C2 = 1 µF, with R4/C5,
C9 = 330 pF, and R10/C7 present. The fallback netlist now has the same topology
and component references. No external source/cable/ADC impedance is modeled.

This adapted model is not an official TI model. Its noise and ESD/protection
behavior are not vendor-accurate. No new TI-model transient run is claimed.
For a self-contained current-topology AC simulation, use `AC_SIM/`; see
[SIMULATION_SPLIT.md](SIMULATION_SPLIT.md).

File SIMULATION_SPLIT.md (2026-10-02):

# Simulation paths and current circuit

The root and AC projects now share the current hardware schematic topology and
reference designators. Both default to **10.10 dB / C2 MLCC**. Both standalone
reference netlists have also been updated. This update does not synchronize
future edits automatically: make subsequent hardware changes in both projects
or derive a fresh AC schematic from the root again.

## Root: TI-based transient model

`SC440_Preamp.kicad_sch` / `SC440_Preamp.wbk` use the locally generated
`vendor/OPA167x_ngspice.LIB`. Generate it with `tools/prepare_ti_model.py` as
shown in the root README. `SC440_Preamp_fallback.cir` is a current-topology
standalone fallback using the same model.

Model order: `OPA167x IN+ IN- VCC VEE OUT`. The intended instance connections
are, allowing for exporter-selected net spelling:

```spice
XREF1 VREF_RAW VREF VCC_A 0 VREF OPA167x
XAMP1 IN_AC FB VCC_A 0 PREAMP_OUT OPA167x
```

The virtual symbol mapping is `1=OUT 2=VEE 3=IN+ 4=IN- 5=VCC`. Its physical
U1 counterpart is excluded from simulation. Use the TI-based path for
operating-point/transient investigations within the adapted model's limits.
The model converter changes syntax and protection/noise cells; it is not a
vendor-accurate noise or ESD model, nor a compatibility guarantee for every
ngspice build. No TI-model transient run was performed for this update because
the vendor model is not included.

## AC_SIM: included small-signal model

`AC_SIM/SC440_Preamp_AC.kicad_sch` / `.wbk` use the included
`vendor/OPA1678_AC_ngspice.lib`. The two virtual op-amp symbols use
**`Sim.Pins = 1=5 2=4 3=1 4=2 5=3`**, matching their current symbol pins to the
subcircuit order `INP INM VCC VEE OUT`.

```spice
XREF1 VREF_RAW VREF VCC_A 0 VREF OPA1678_AC
XAMP1 IN_AC FB VCC_A 0 PREAMP_OUT OPA1678_AC
```

Model assumptions:

- Typical open-loop gain 114 dB (501187 V/V), GBW 16 MHz.
- One dominant pole near 31.9 Hz; 10 Ω output resistance.
- 10 TΩ differential input resistance and tiny supply-reference paths.
- No rail limits, clipping, slew, noise or PSRR model.

The AC source amplitude is 1 V. The workbook sweeps 0.1 Hz to 10 MHz and plots
`V(/ANALOG_OUTPUT)` magnitude/phase and `V(/PREAMP_OUT)` magnitude. Additional
normalized expressions, if desired, are:

```text
db(V(/ANALOG_OUTPUT) / V(/ANALOG_INPUT))
db(V(/PREAMP_OUT) / V(/IN_AC))
```

The model includes the current 22 Ω supply feed, buffered divider, R4/C5 input
filter, R8/R9 feedback, C9, and R10/C7 output filter. Neither the original source
impedance nor cable/ADC loading is modeled. The standalone reference netlist
uses ground `0`; KiCad schematics use power:GND and the exporter's ground
handling. This linear model does not constrain output voltage to the supply
rails, so it cannot assess clipping or DC headroom.

## Validation

Hardware values/DNP flags, U1 physical pins, and virtual model pin order were
cross-checked between both schematics, the PCB and the standalone netlists.
See [FOOTPRINT_CHECK.md](FOOTPRINT_CHECK.md).

Standalone AC runs and the calculated 6/8/10 dB, MLCC/film assembly comparisons
are documented in [SIMULATION_VALIDATION.md](SIMULATION_VALIDATION.md). KiCad
10.99 GUI/workbook loading and the TI macro-model path were not executed in the
editing environment. Successful standalone AC analysis does not validate
physical EMI performance, noise or ADC loading.

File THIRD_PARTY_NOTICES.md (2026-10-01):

# Third-party notices

## Texas Instruments OPA167x TINA-TI model

The root KiCad simulation is designed to use Texas Instruments' OPA167x
TINA-TI macro-model (download package `SBOMAC5D`). The TI model itself, and the
ngspice-adapted file generated from it, are **not included in this repository**.

Users obtain the model directly from Texas Instruments and locally run
`tools/prepare_ti_model.py`. The resulting `vendor/OPA167x_ngspice.LIB` remains
a derivative/adapted copy of the TI model and is Git-ignored.

The conversion script is project-authored and contains only the compatibility
transformation logic. It does not contain a copy of the TI macro-model.

Texas Instruments and OPA167x/OPA1678 are identifiers/trademarks of their
respective owner. This project is not affiliated with or endorsed by Texas
Instruments.

## Simplified AC model

`AC_SIM/vendor/OPA1678_AC_ngspice.lib` is a project-authored simplified
small-signal model based on publicly documented typical device parameters. It
is not a Texas Instruments macro-model and must not be used as a substitute for
vendor-accurate large-signal, noise, clipping, or protection behavior.

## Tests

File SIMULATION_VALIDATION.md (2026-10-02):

# Current AC simulation validation

Validation date: **2026-10-02**. Engine: **ngspice 42**. Model:
`AC_SIM/vendor/OPA1678_AC_ngspice.lib`, the included project-authored,
linear small-signal model. This is a simulation of nominal components, not a
measurement of the microphone.

## Connectivity and model checks

- Root and AC schematics have matching hardware values, pin connectivity and
  assembly/simulation flags. C4/C8 are included in the BOM.
- Every physical schematic pin was checked against the corresponding PCB pad
  net, including the connectors, U1 supplies and both op-amp channels.
- AC virtual symbols map correctly into the model order `INP INM VCC VEE OUT`:
  `Sim.Pins = 1=5 2=4 3=1 4=2 5=3`.
- A verification netlist derived independently from the AC schematic's symbol
  pins and wires was simulated and compared with the standalone reference.
  Over 0.1 Hz to 10 MHz, the reported output gain and phase agree within
  **0.000001 dB / 0.000001°** (output-file rounding).

## Six assembly variants

Sweeps: **0.1 Hz to 10 MHz, 1000 points/decade**. R9 = 1 kΩ and C9 = 330 pF
in every run. Ideal zero-impedance input source, AC amplitude 1 V. No external
output load. The film run replaces C2 with a 2.2 µF capacitor; R1/R2 are
represented by ideal wires.

| Gain option | Input option | R8 | Gain at 1 kHz | Gain at 20 kHz | Low-frequency −3 dB point |
|---|---|---:|---:|---:|---:|
| 6 dB | MLCC (1 µF) | 1 kΩ | 5.931 dB | 5.917 dB | 1.579 Hz |
| 6 dB | Film (2.2 µF) | 1 kΩ | 5.933 dB | 5.919 dB | 0.718 Hz |
| 8 dB | MLCC (1 µF) | 1.5 kΩ | 7.869 dB | 7.846 dB | 1.579 Hz |
| 8 dB | Film (2.2 µF) | 1.5 kΩ | 7.871 dB | 7.848 dB | 0.718 Hz |
| 10 dB | MLCC (1 µF) | 2.2 kΩ | 10.014 dB | 9.971 dB | 1.579 Hz |
| 10 dB | Film (2.2 µF) | 2.2 kΩ | 10.015 dB | 9.973 dB | 0.718 Hz |

Gain is measured from ANALOG_INPUT to ANALOG_OUTPUT. The low-frequency point
is relative to the same variant's gain at 1 kHz. Reported precision describes
the numerical result; component tolerances and real loading are not included.

R4/R6 introduce approximately `20·log10(100k/101k) = −0.086 dB` before the
amplifier. Coupling capacitance, C5, finite op-amp gain/bandwidth, C9 and R10/C7
also contribute. This explains why the amplifier's nominal +10.10 dB becomes
about +10.01 dB end to end. From 1 to 20 kHz the simulated change is about
−0.014 / −0.023 / −0.043 dB for the 6 / 8 / 10 dB options.

The input high-pass estimates `1/(2π·101k·C)` are 1.576 Hz for 1 µF and
0.716 Hz for 2.2 µF, consistent with the simulated lower cutoffs.

## Reproduce with standalone ngspice

From the project root:

```sh
cd AC_SIM
ngspice SC440_Preamp_AC_reference.cir
```

At the ngspice prompt, the following selects a denser sweep and prints the
default assembly's gain:

```text
ac dec 1000 0.1 10Meg
let output_gain = db(v(ANALOG_OUTPUT))
meas ac gain_1k find output_gain at=1k
meas ac gain_20k find output_gain at=20k
```

For another assembly, first use `alter R8=1k` or `alter R8=1.5k`. To represent
the film coupling electrically, use `alter C2=2.2u`. Then repeat the four
commands above. This command changes the simulation capacitance only; the
physical film assembly uses C1/R1/R2 and leaves C2 unpopulated.

## Scope

The standalone AC runs passed. KiCad 10.99 GUI/workbook loading and a new run
of the separately prepared TI macro-model were **not** performed. No new KiCad
ERC/DRC run is claimed. The linear AC model does not establish noise, clipping,
slew rate, PSRR, EMI immunity or stability with arbitrary real cable/ADC loads.
The input-source impedance and the digital board's coupling capacitor/input
impedance remain outside this simulation.

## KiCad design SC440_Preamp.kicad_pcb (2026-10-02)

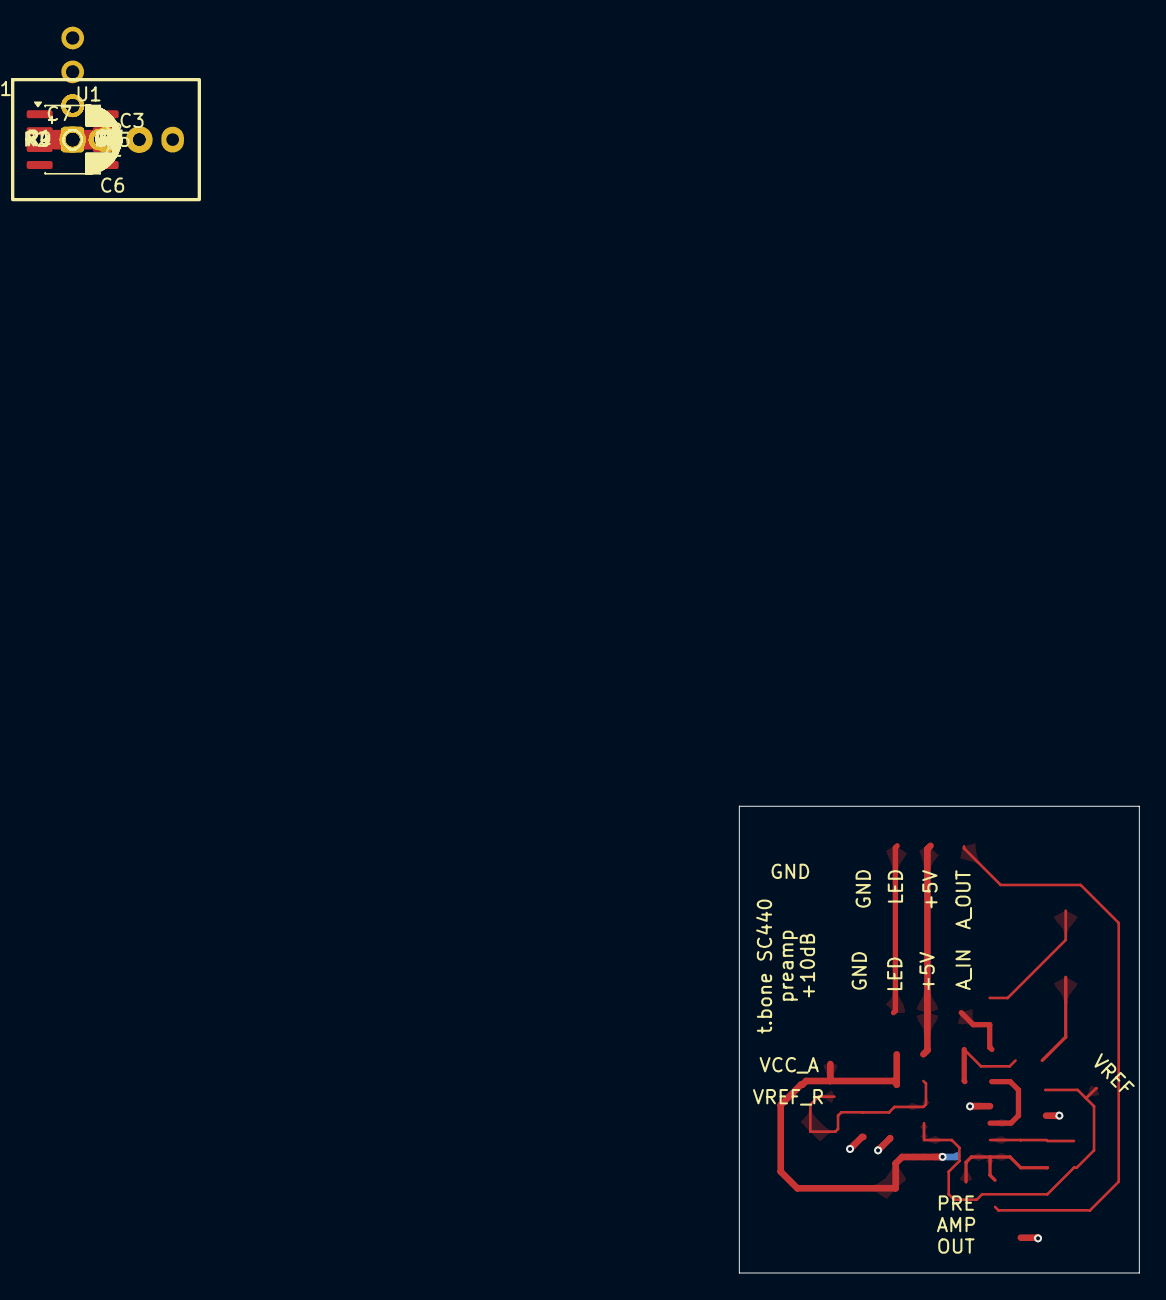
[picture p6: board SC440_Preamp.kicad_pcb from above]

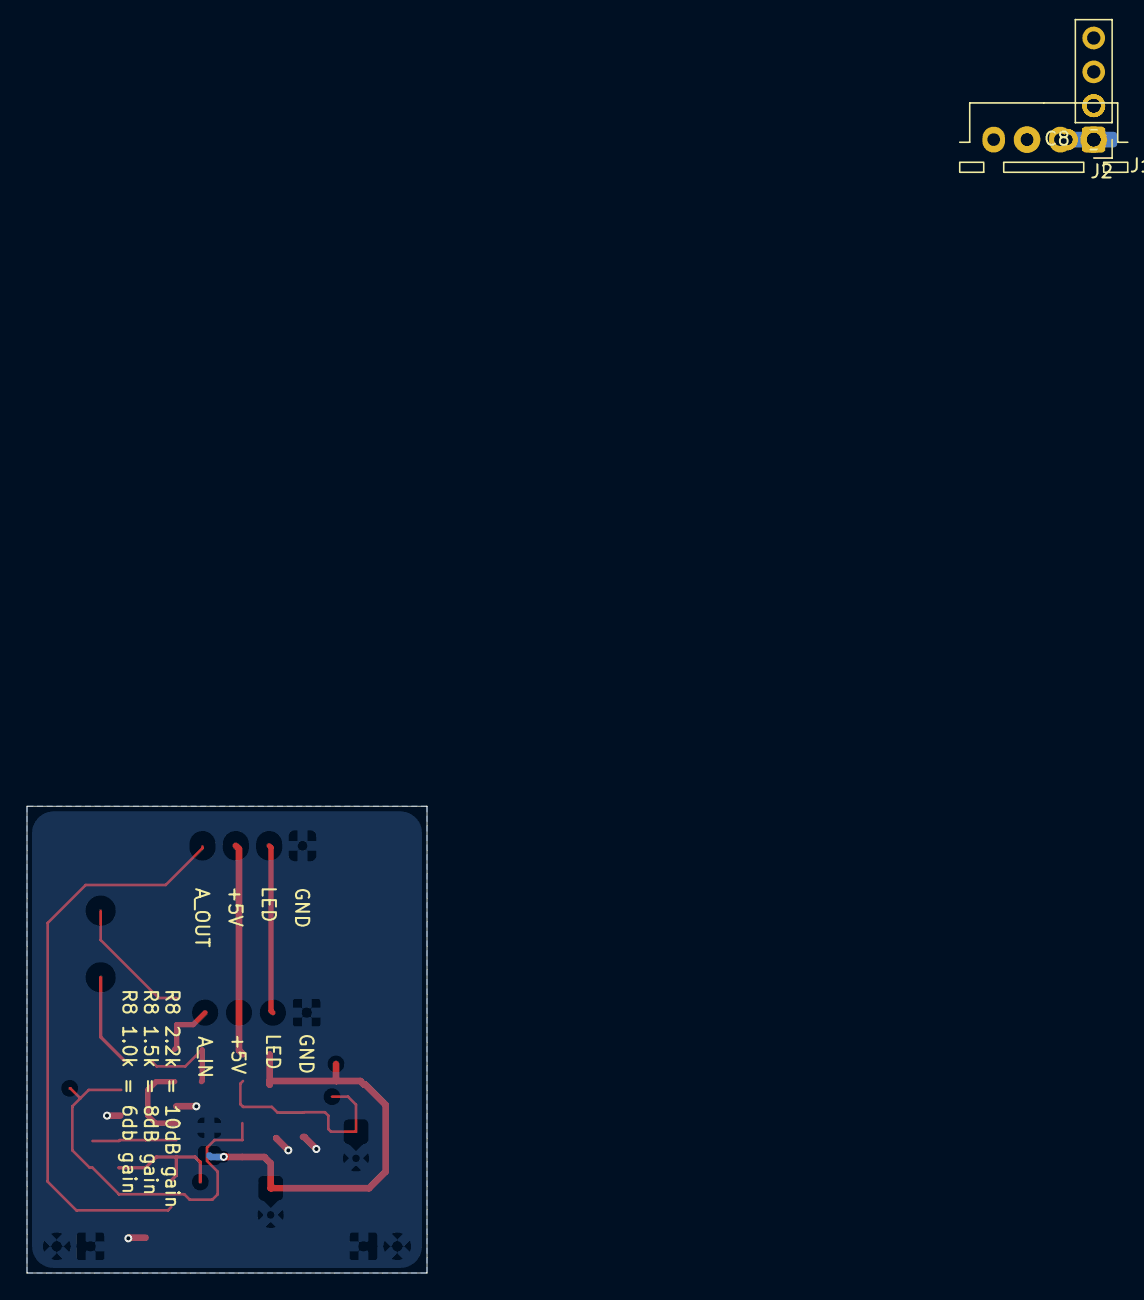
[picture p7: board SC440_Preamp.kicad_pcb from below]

Board: 2 copper layers, 30.0 x 35.0 mm, 27 parts (3 on the bottom side), 14 nets.

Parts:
C1: 2.2u; Faratronic_C241J225_P5.00mm
C2: 1u; C_0805_2012Metric_Pad1.18x1.45mm_HandSolder
C3: 47u; CP_Radial_D5.0mm_P2.00mm
C4, C8: 100n; C_0805_2012Metric_Pad1.18x1.45mm_HandSolder
C5, C9: 330p; C_0805_2012Metric_Pad1.18x1.45mm_HandSolder
C6: 10u; CP_Radial_D5.0mm_P2.00mm
C7: 1n; C_0805_2012Metric_Pad1.18x1.45mm_HandSolder
J1: JST-XH 1x04 TO DIGITAL BOARD; JST_XH_B4B-XH-A_1x04_P2.50mm_Vertical
J2: ANALOG BOARD; PinHeader_1x04_P2.54mm_Vertical
R1, R2: 0; R_0805_2012Metric_Pad1.20x1.40mm_HandSolder
R3: 22R; R_0805_2012Metric_Pad1.20x1.40mm_HandSolder
R4, R9: 1k; R_0805_2012Metric_Pad1.20x1.40mm_HandSolder
R5, R7: 10k; R_0805_2012Metric_Pad1.20x1.40mm_HandSolder
R6: 100k; R_0805_2012Metric_Pad1.20x1.40mm_HandSolder
R8: 2.2k; R_0805_2012Metric_Pad1.20x1.40mm_HandSolder
R10: 100R; R_0805_2012Metric_Pad1.20x1.40mm_HandSolder
TP1, TP2, TP3, TP4, TP5: TestPoint; TestPoint_THTPad_D1.0mm_Drill0.5mm
U1: OPA1678IDR; SOIC-8_3.9x4.9mm_P1.27mm

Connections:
+5V: J1.3 (+5V), J2.3 (+5V), R3.1
/ANALOG_INPUT: C2.1, J2.4 (OUT), R1.2
/ANALOG_OUTPUT: C7.1, J1.4 (IN), R10.2
/FB: C9.1, R8.1, R9.2, U1.2 (-A)
/IN_AC: C5.1, R4.2, R6.1, U1.3 (+A)
/LED: J1.2 (LED), J2.2 (LED)
/PREAMP_OUT: C9.2, R8.2, R10.1, TP4.1 (1_1), U1.1 (OUT_A)
/VCC_A: C6.1 (+), C8.1, R3.2, R5.2, TP1.1 (1_1), U1.8 (V+)
/VREF: R6.2, R9.1, TP3.1 (1_1), U1.6 (-B), U1.7 (OUT_B)
/VREF_RAW: C3.1 (+), C4.1, R5.1, R7.1, TP2.1 (1_1), U1.5 (+B)
GND: C3.2 (-), C4.2, C5.2, C6.2 (-), C7.2, C8.2, J1.1 (GND), J2.1 (GND), R7.2, TP5.1 (1_1), U1.4 (V-)
unnamed: C1.1, R1.1
unnamed: C1.2, R2.1
unnamed: C2.2, R2.2, R4.1

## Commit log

2026-10-01 some minor modifications
    [SC440_Preamp.kicad_pcb]
2026-10-01 fix spice tool and pin assignments
    [SC440_Preamp.kicad_sch]
2026-10-01 add input and output filter
    [SC440_Preamp.kicad_pcb, SC440_Preamp.kicad_sch]
2026-10-02 add more filtering, silkscreen, pinsockets as spacers
    [SC440_Preamp.kicad_pcb, SC440_Preamp.kicad_sch]
2026-10-02 add script to regenerate current pics
2026-10-02 clean up pcb images
2026-10-02 docs: update BOM and assembly variants; sync and fix simulations
    - Document current hardware, MLCC/film options and 6/8/10 dB variants
    - Synchronize AC project and reference netlists with current schematic
    - Include C4/C8 in BOM and exclude test points from SPICE export
    - Validate connectivity and all six AC assembly variants
    [SC440_Preamp.kicad_pcb, SC440_Preamp.kicad_sch, SC440_Preamp_AC.kicad_sch]
2026-10-02 this project won't really help
    [SC440_Preamp.kicad_pcb, SC440_Preamp.kicad_sch]
